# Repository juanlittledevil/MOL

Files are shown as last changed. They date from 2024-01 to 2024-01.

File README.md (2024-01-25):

# MOL

Dual ADSR/VCA combo module for Eurorack.

For more details check my blog post here: www.scruffycatstudios.com/posts/degvca/
part 2 here: www.scruffycatstudios.com/posts/degvca-part2/
And YouTube here: https://www.youtube.com/watch?v=CZ0J_sP1nE4&list=PLdO1IhDAhMdK4l8dJ0V3lOzin-maOEFXo

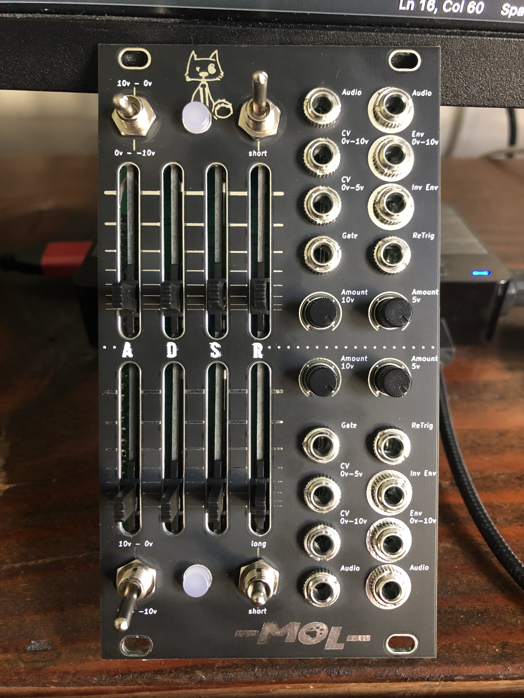
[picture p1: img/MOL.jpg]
MOL


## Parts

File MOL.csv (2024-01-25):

Source: | /Users/juan/KiCad/projects/DEGVCA/DEGVCA.kicad_sch
Date: | 2023 December 11, Monday 09:53:17
Tool: | Eeschema 7.0.1-0
Generator: | /Applications/KiCad/KiCad.app/Contents/SharedSupport/plugins/bom_csv_grouped_by_value.py
Component Count: | 174
Collated Components:
Item | Qty | Reference(s) | Value | LibPart | Footprint | Datasheet | DNP
1 | 6 | C1, C2, C8, C9, C19, C20 | 10n | *SCS:C-THL | Capacitor_THT:C_Disc_D4.3mm_W1.9mm_P5.00mm | ~
2 | 10 | C3, C4, C11, C12, C13, C14, C15, C16, C17, C18 | 100n | *SCS:C-THL | Capacitor_THT:C_Disc_D4.3mm_W1.9mm_P5.00mm | ~
3 | 2 | C5, C10 | 47uF | *SCS:C_Polarized_THL | Capacitor_THT:CP_Radial_D5.0mm_P2.50mm | ~
4 | 2 | C6, C7 | 10uF | Device:C_Polarized | Capacitor_THT:CP_Radial_D5.0mm_P2.50mm | ~
5 | 2 | C21, C22 | 1n | *SCS:C-THL | Capacitor_THT:C_Disc_D4.3mm_W1.9mm_P5.00mm | ~
6 | 2 | C23, C24 | 1u | *SCS:C-THL | Capacitor_THT:C_Disc_D4.3mm_W1.9mm_P5.00mm | ~
7 | 2 | D1, D2 | Schottky | *SCS:D_Schottky-THL | *SCS_ScruffyCat:D_DO-35_SOD27_P2.54mm_Vertical_KathodeUp | ~
8 | 16 | D3, D4, D5, D6, D7, D8, D9, D10, D11, D12, D13, D14, D15, D16, D17, D18 | 1N4148 | *SCS:D-THL | *SCS_ScruffyCat:D_DO-35_SOD27_P2.54mm_Vertical_KathodeUp | ~
9 | 1 | D19 | LED A | *SCS:LED | LED_THT:LED_D3.0mm | ~
10 | 1 | D20 | LED B | *SCS:LED | LED_THT:LED_D3.0mm | ~
11 | 2 | FB1, FB2 | FerriteBead | Device:FerriteBead | Resistor_THT:R_Axial_DIN0411_L9.9mm_D3.6mm_P5.08mm_Vertical | ~
12 | 1 | J1 | EuroRack Power | Connector_Generic:Conn_02x05_Odd_Even | Connector_IDC:IDC-Header_2x05_P2.54mm_Vertical | ~
13 | 1 | J2 | Gate In A | *SCS:Audio_Jack_Switch | *SCS_ScruffyCat:Jack_3.5mm_QingPu_thonk-PJ398SM_Vertical_CircularHoles | ~
14 | 1 | J3 | Gate In B | *SCS:Audio_Jack_Switch | *SCS_ScruffyCat:Jack_3.5mm_QingPu_thonk-PJ398SM_Vertical_CircularHoles | ~
15 | 1 | J4 | Audio In A | *SCS:Audio_Jack_Switch | *SCS_ScruffyCat:Jack_3.5mm_QingPu_thonk-PJ398SM_Vertical_CircularHoles | ~
16 | 1 | J5 | Audio In B | *SCS:Audio_Jack_Switch | *SCS_ScruffyCat:Jack_3.5mm_QingPu_thonk-PJ398SM_Vertical_CircularHoles | ~
17 | 1 | J6 | Audio Out A | *SCS:Audio_Jack_Switch | *SCS_ScruffyCat:Jack_3.5mm_QingPu_thonk-PJ398SM_Vertical_CircularHoles | ~
18 | 1 | J7 | Audio Out B | *SCS:Audio_Jack_Switch | *SCS_ScruffyCat:Jack_3.5mm_QingPu_thonk-PJ398SM_Vertical_CircularHoles | ~
19 | 1 | J8 | Inv CV Out A (10v - 0v) | *SCS:Audio_Jack_Switch | *SCS_ScruffyCat:Jack_3.5mm_QingPu_thonk-PJ398SM_Vertical_CircularHoles | ~
20 | 1 | J9 | Inv CV Out B (10v - 0v) | *SCS:Audio_Jack_Switch | *SCS_ScruffyCat:Jack_3.5mm_QingPu_thonk-PJ398SM_Vertical_CircularHoles | ~
21 | 1 | J10 | CV Out A (0v - 10v) | *SCS:Audio_Jack_Switch | *SCS_ScruffyCat:Jack_3.5mm_QingPu_thonk-PJ398SM_Vertical_CircularHoles | ~
22 | 1 | J11 | CV Out B (0v - 10v) | *SCS:Audio_Jack_Switch | *SCS_ScruffyCat:Jack_3.5mm_QingPu_thonk-PJ398SM_Vertical_CircularHoles | ~
23 | 1 | J12 | CV In A (0v - 5v) | *SCS:Audio_Jack_Switch | *SCS_ScruffyCat:Jack_3.5mm_QingPu_thonk-PJ398SM_Vertical_CircularHoles | ~
24 | 1 | J13 | CV In B (0v - 5v) | *SCS:Audio_Jack_Switch | *SCS_ScruffyCat:Jack_3.5mm_QingPu_thonk-PJ398SM_Vertical_CircularHoles | ~
25 | 1 | J14 | Re-Trigger A | *SCS:Audio_Jack_Switch | *SCS_ScruffyCat:Jack_3.5mm_QingPu_thonk-PJ398SM_Vertical_CircularHoles | ~
26 | 1 | J15 | Re-Trigger B | *SCS:Audio_Jack_Switch | *SCS_ScruffyCat:Jack_3.5mm_QingPu_thonk-PJ398SM_Vertical_CircularHoles | ~
27 | 1 | J16 | CV In A (0v - 10v) | *SCS:Audio_Jack_Switch | *SCS_ScruffyCat:Jack_3.5mm_QingPu_thonk-PJ398SM_Vertical_CircularHoles | ~
28 | 1 | J17 | CV In B (0v - 10v) | *SCS:Audio_Jack_Switch | *SCS_ScruffyCat:Jack_3.5mm_QingPu_thonk-PJ398SM_Vertical_CircularHoles | ~
29 | 4 | J18, J19, J20, J21 | Screw Hole | Connector:Conn_01x01_Female | *SCS_ScruffyCat:ScrewHole_Oval | ~
30 | 8 | Q1, Q2, Q3, Q4, Q5, Q6, Q9, Q10 | BC547 | Transistor_BJT:BC547 | Package_TO_SOT_THT:TO-92_Wide | https://www.onsemi.com/pub/Collateral/BC550-D.pdf
31 | 2 | Q7, Q8 | 2N3906 | Transistor_BJT:2N3906 | Package_TO_SOT_THT:TO-92_Wide | https://www.onsemi.com/pub/Collateral/2N3906-D.PDF
32 | 6 | R1, R2, R6, R18, R55, R57 | 10k | *SCS:R-THL | Resistor_THT:R_Axial_DIN0207_L6.3mm_D2.5mm_P2.54mm_Vertical | ~
33 | 6 | R3, R5, R7, R15, R17, R19 | 4.7k | *SCS:R-THL | Resistor_THT:R_Axial_DIN0207_L6.3mm_D2.5mm_P2.54mm_Vertical | ~
34 | 2 | R4, R16 | 22k | *SCS:R-THL | Resistor_THT:R_Axial_DIN0207_L6.3mm_D2.5mm_P2.54mm_Vertical | ~
35 | 6 | R8, R9, R11, R20, R21, R22 | 22 | *SCS:R-THL | Resistor_THT:R_Axial_DIN0207_L6.3mm_D2.5mm_P2.54mm_Vertical | ~
36 | 2 | R10, R23 | 27k | *SCS:R-THL | Resistor_THT:R_Axial_DIN0207_L6.3mm_D2.5mm_P2.54mm_Vertical | ~
37 | 8 | R12, R26, R30, R33, R42, R44, R47, R53 | 1k | *SCS:R-THL | Resistor_THT:R_Axial_DIN0207_L6.3mm_D2.5mm_P2.54mm_Vertical | ~
38 | 2 | R13, R24 | 39k | *SCS:R-THL | Resistor_THT:R_Axial_DIN0207_L6.3mm_D2.5mm_P2.54mm_Vertical | ~
39 | 2 | R14, R25 | 150k | *SCS:R-THL | Resistor_THT:R_Axial_DIN0207_L6.3mm_D2.5mm_P2.54mm_Vertical | ~
40 | 16 | R27, R36, R45, R46, R52, R54, R59, R60, R61, R62, R64, R65, R71, R72, R73, R74 | 100k | *SCS:R-THL | Resistor_THT:R_Axial_DIN0207_L6.3mm_D2.5mm_P2.54mm_Vertical | ~
41 | 4 | R28, R29, R37, R38 | 330 | *SCS:R-THL | Resistor_THT:R_Axial_DIN0207_L6.3mm_D2.5mm_P2.54mm_Vertical | ~
42 | 2 | R31, R43 | 36k | *SCS:R-THL | Resistor_THT:R_Axial_DIN0207_L6.3mm_D2.5mm_P2.54mm_Vertical | ~
43 | 2 | R32, R41 | 6.8k | *SCS:R-THL | Resistor_THT:R_Axial_DIN0207_L6.3mm_D2.5mm_P2.54mm_Vertical | ~
44 | 2 | R34, R40 | 33k | *SCS:R-THL | Resistor_THT:R_Axial_DIN0207_L6.3mm_D2.5mm_P2.54mm_Vertical | ~
45 | 7 | R35, R39, R51, R63, R66, R67, R68 | 330k | *SCS:R-THL | Resistor_THT:R_Axial_DIN0207_L6.3mm_D2.5mm_P2.54mm_Vertical | ~
46 | 1 | R48 | 68k | *SCS:R-THL | Resistor_THT:R_Axial_DIN0207_L6.3mm_D2.5mm_P2.54mm_Vertical | ~
47 | 1 | R49 | 47k | *SCS:R-THL | Resistor_THT:R_Axial_DIN0207_L6.3mm_D2.5mm_P2.54mm_Vertical | ~
48 | 1 | R50 | 470k | *SCS:R-THL | Resistor_THT:R_Axial_DIN0207_L6.3mm_D2.5mm_P2.54mm_Vertical | ~
49 | 4 | R56, R58, R69, R70 | 220 | *SCS:R-THL | Resistor_THT:R_Axial_DIN0207_L6.3mm_D2.5mm_P2.54mm_Vertical | ~
50 | 1 | REF_ADJ_A1 | 5k | Device:R_Potentiometer_Trim | *SCS_ScruffyCat:Potentiometer_Trim_Vertical_THL | ~
51 | 1 | RV1 | Attack A | *SCS:R_Potentiometer-THL | Potentiometer_THT:Potentiometer_Alpha_RD901F-40-00D_Single_Vertical_CircularHoles | ~
52 | 3 | RV2, RV4, RV8 | Decay A | *SCS:R_Potentiometer-THL | Potentiometer_THT:Potentiometer_Alpha_RD901F-40-00D_Single_Vertical_CircularHoles | ~
53 | 1 | RV3 | Sustain A | *SCS:R_Potentiometer-THL | Potentiometer_THT:Potentiometer_Alpha_RD901F-40-00D_Single_Vertical_CircularHoles | ~
54 | 1 | RV5 | Attack B | *SCS:R_Potentiometer-THL | Potentiometer_THT:Potentiometer_Alpha_RD901F-40-00D_Single_Vertical_CircularHoles | ~
55 | 1 | RV6 | Decay B | *SCS:R_Potentiometer-THL | Potentiometer_THT:Potentiometer_Alpha_RD901F-40-00D_Single_Vertical_CircularHoles | ~
56 | 1 | RV7 | Sustain B | *SCS:R_Potentiometer-THL | Potentiometer_THT:Potentiometer_Alpha_RD901F-40-00D_Single_Vertical_CircularHoles | ~
57 | 4 | RV9, RV10, RV11, RV12 | 100k | *SCS:R_Potentiometer-THL | Potentiometer_THT:Potentiometer_Alpha_RD901F-40-00D_Single_Vertical_CircularHoles | ~
58 | 2 | SW1, SW2 | SW_Push_LED | Switch:SW_Push_LED | *SCS_ScruffyCat:SW_PushButton_LED_E-Type-A | ~
59 | 1 | SW3 | Inv Offset A | *SCS:SW_SPDT | *SCS_ScruffyCat:SW_Toggle_Blue_wSlots | ~
60 | 1 | SW4 | Inv Offset B | *SCS:SW_SPDT | *SCS_ScruffyCat:SW_Toggle_Blue_wSlots | ~
61 | 1 | TP1-(5v)1 | TestPoint | Connector:TestPoint | Connector_Pin:Pin_D0.9mm_L10.0mm_W2.4mm_FlatFork | ~
62 | 1 | U1 | LM556 | *SCS:LM556 | Package_DIP:DIP-14_W7.62mm_Socket | http://www.ti.com/lit/ds/symlink/lm556.pdf
63 | 3 | U2, U4, U5 | TL074 | *SCS:TL074 |  | http://www.ti.com/lit/ds/symlink/tl071.pdf
64 | 1 | U3 | LM13700 | Amplifier_Operational:LM13700 |  | http://www.ti.com/lit/ds/symlink/lm13700.pdf

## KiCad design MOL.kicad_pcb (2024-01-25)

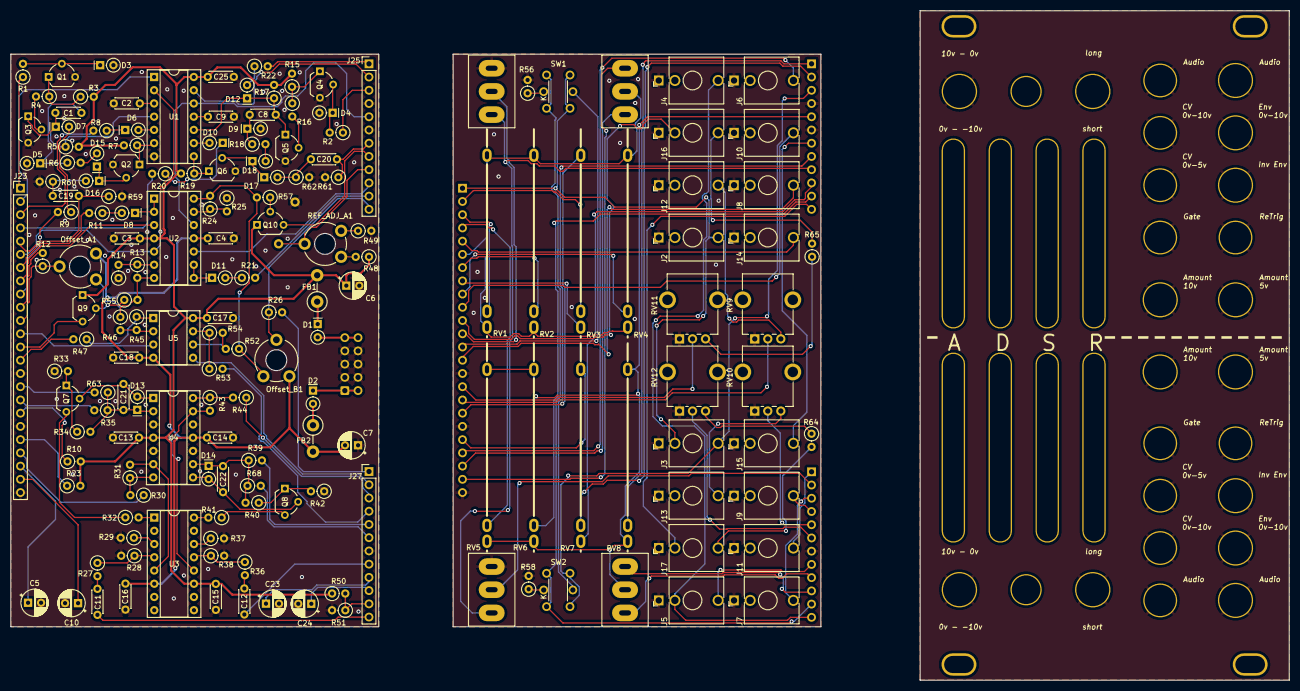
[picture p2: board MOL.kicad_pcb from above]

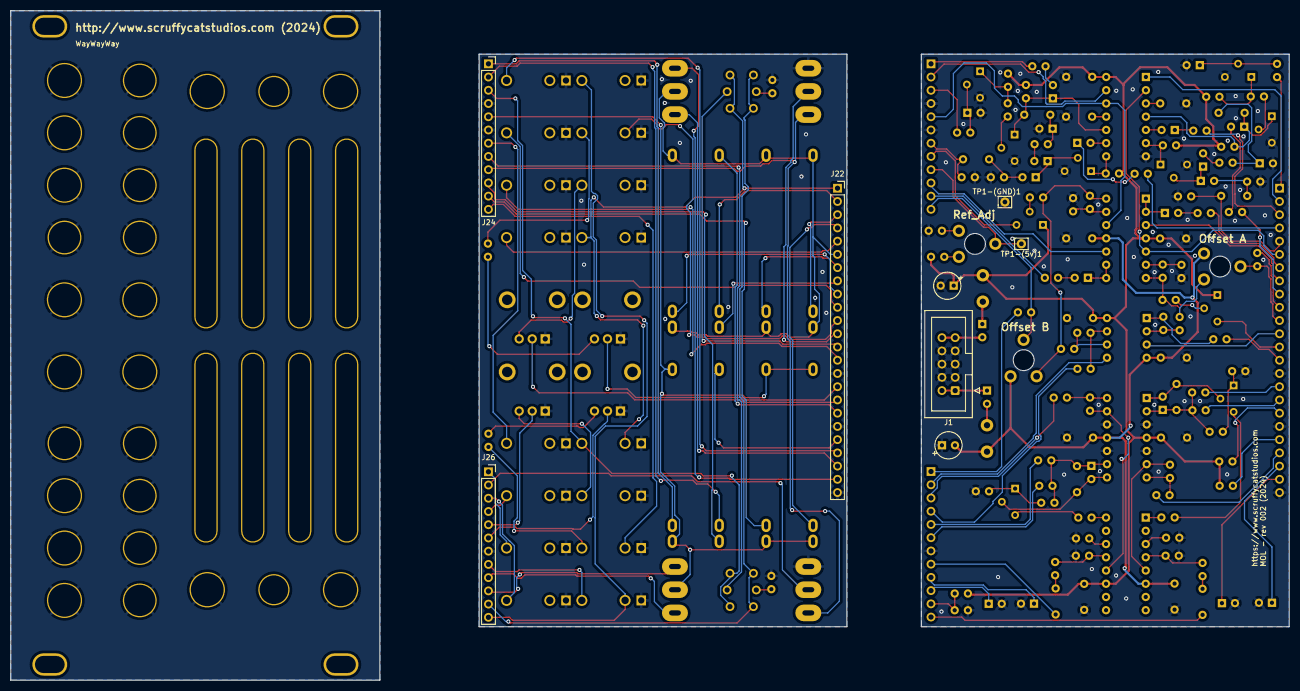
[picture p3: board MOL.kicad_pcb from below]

Board: 2 copper layers, 245.4 x 128.5 mm, 210 parts (6 on the bottom side), 161 nets.

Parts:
BH1, BH2: LED Button; LED-ButtonHole
C1, C2, C8, C9, C19, C20: 10n; C_Disc_D4.3mm_W1.9mm_P5.00mm
C3, C4, C11, C12, C13, C14, C15, C16, C17, C18, C25: 100n; C_Disc_D4.3mm_W1.9mm_P5.00mm
C5, C23: 47uF; CP_Radial_D5.0mm_P2.50mm
C6, C7: 10uF; CP_Radial_D5.0mm_P2.50mm
C10, C24: 4.7uF; CP_Radial_D5.0mm_P2.50mm
C21, C22: 1n; C_Disc_D4.3mm_W1.9mm_P5.00mm
D1, D2: Schottky; D_DO-35_SOD27_P2.54mm_Vertical_KathodeUp
D3, D4, D5, D6, D7, D8, D9, D10, D11, D12, D13, D14, D15, D16, D17, D18: 1N4148; D_DO-35_SOD27_P2.54mm_Vertical_KathodeUp
FB1, FB2: FerriteBead; R_Axial_DIN0411_L9.9mm_D3.6mm_P5.08mm_Vertical
J1: EuroRack Power; IDC-Header_2x05_P2.54mm_Vertical
J2: Gate In A; Jack_3.5mm_QingPu_thonk-PJ398SM_Vertical_CircularHoles
J3: Gate In B; Jack_3.5mm_QingPu_thonk-PJ398SM_Vertical_CircularHoles
J4: Audio In A_(C); Jack_3.5mm_QingPu_thonk-PJ398SM_Vertical_CircularHoles
J5: Audio In B_(C); Jack_3.5mm_QingPu_thonk-PJ398SM_Vertical_CircularHoles
J6: Audio Out A_(C); Jack_3.5mm_QingPu_thonk-PJ398SM_Vertical_CircularHoles
J7: Audio Out B_(C); Jack_3.5mm_QingPu_thonk-PJ398SM_Vertical_CircularHoles
J8: Inv CV Out A (10v - 0v); Jack_3.5mm_QingPu_thonk-PJ398SM_Vertical_CircularHoles
J9: Inv CV Out B (10v - 0v); Jack_3.5mm_QingPu_thonk-PJ398SM_Vertical_CircularHoles
J10: CV Out A (0v - 10v); Jack_3.5mm_QingPu_thonk-PJ398SM_Vertical_CircularHoles
J11: CV Out B (0v - 10v); Jack_3.5mm_QingPu_thonk-PJ398SM_Vertical_CircularHoles
J12: CV In A (0v - 5v); Jack_3.5mm_QingPu_thonk-PJ398SM_Vertical_CircularHoles
J13: CV In B (0v - 5v); Jack_3.5mm_QingPu_thonk-PJ398SM_Vertical_CircularHoles
J14: Re-Trigger A_(C); Jack_3.5mm_QingPu_thonk-PJ398SM_Vertical_CircularHoles
J15: Re-Trigger B_(C); Jack_3.5mm_QingPu_thonk-PJ398SM_Vertical_CircularHoles
J16: CV In A (0v - 10v); Jack_3.5mm_QingPu_thonk-PJ398SM_Vertical_CircularHoles
J17: CV In B (0v - 10v); Jack_3.5mm_QingPu_thonk-PJ398SM_Vertical_CircularHoles
J18, J19, J20, J21: Screw Hole; ScrewHole_Oval
J22: Conn_01x24_Socket; PinSocket_1x24_P2.54mm_Vertical
J23: Conn_01x24_Pin; PinHeader_1x24_P2.54mm_Vertical
J24, J26: Conn_01x12_Socket; PinSocket_1x12_P2.54mm_Vertical
J25, J27: Conn_01x12_Pin; PinHeader_1x12_P2.54mm_Vertical
JH1, JH2, JH3, JH4, JH7, JH9, JH10, JH11, JH12, JH14: 3.5mm Jack; JackHole_3.5mm
JH5, JH6, JH8, JH13, JH15, JH16: 3.5mm Jack; JackHole_3.5mm-OUT
Offset_A1: 5k; Potentiometer_Trim_Vertical_THL
Offset_B1: 5k; Potentiometer_Trim_Vertical_THL
PH1, PH2, PH3, PH4, PH5, PH6, PH7, PH8: 30mm Vertical Slider; PotHole_Slide_open_oval
PH9, PH10, PH11, PH12: Pot Jack (no-mount); PotHole_no-mount
Q1, Q2, Q3, Q4, Q5, Q6, Q9, Q10: BC547; TO-92_Wide
Q7, Q8: 2N3906; TO-92_Wide
R1, R2, R6, R18, R55, R57: 10k; R_Axial_DIN0207_L6.3mm_D2.5mm_P2.54mm_Vertical
R3, R5, R7, R15, R17, R19: 4.7k; R_Axial_DIN0207_L6.3mm_D2.5mm_P2.54mm_Vertical
R4, R16: 22k; R_Axial_DIN0207_L6.3mm_D2.5mm_P2.54mm_Vertical
R8, R9, R11, R20, R21, R22: 22; R_Axial_DIN0207_L6.3mm_D2.5mm_P2.54mm_Vertical
R10, R23, R49: 27k; R_Axial_DIN0207_L6.3mm_D2.5mm_P2.54mm_Vertical
R12, R26, R30, R33, R42, R44, R47, R53: 1k; R_Axial_DIN0207_L6.3mm_D2.5mm_P2.54mm_Vertical
R13, R24, R31, R43, R48: 39k; R_Axial_DIN0207_L6.3mm_D2.5mm_P2.54mm_Vertical
R14, R25: 150k; R_Axial_DIN0207_L6.3mm_D2.5mm_P2.54mm_Vertical
R27, R36, R45, R46, R52, R54, R59, R60, R61, R62, R64, R65: 100k; R_Axial_DIN0207_L6.3mm_D2.5mm_P2.54mm_Vertical
R28, R29, R37, R38: 330; R_Axial_DIN0207_L6.3mm_D2.5mm_P2.54mm_Vertical
R32, R41: 6.8k; R_Axial_DIN0207_L6.3mm_D2.5mm_P2.54mm_Vertical
R34, R40: 33k; R_Axial_DIN0207_L6.3mm_D2.5mm_P2.54mm_Vertical
R35, R39, R51, R63, R68: 330k; R_Axial_DIN0207_L6.3mm_D2.5mm_P2.54mm_Vertical
R50: 470k; R_Axial_DIN0207_L6.3mm_D2.5mm_P2.54mm_Vertical
R56, R58: 2.2k; R_Axial_DIN0207_L6.3mm_D2.5mm_P2.54mm_Vertical
REF_ADJ_A1: 5k; Potentiometer_Trim_Vertical_THL
RV1: Attack A; Potentiometer_Slide_open_THL
RV2: Decay A; Potentiometer_Slide_open_THL
RV3: Sustain A; Potentiometer_Slide_open_THL
RV4: Release A; Potentiometer_Slide_open_THL
RV5: Attack B; Potentiometer_Slide_open_THL
RV6: Decay B; Potentiometer_Slide_open_THL
RV7: Sustain B; Potentiometer_Slide_open_THL
RV8: Release B; Potentiometer_Slide_open_THL
RV9, RV10, RV11, RV12: 100k; Potentiometer_Alpha_RD901F-40-00D_Single_Vertical_CircularH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
SH1, SH2, SH3, SH4: Switch Jack; SwitchHole_screw-mount
SW1, SW2: SW_Push_LED; SW_PushButton_LED_E-Type-A
SW3: Inv Offset A; SW_Toggle_Blue_wSlots
SW4: Inv Offset B; SW_Toggle_Blue_wSlots
SW5: Length A; SW_Toggle_Blue_wSlots
SW6: Length B; SW_Toggle_Blue_wSlots
TP1-(5v)1, TP1-(GND)1: TestPoint; Pin_D0.9mm_L10.0mm_W2.4mm_FlatFork
U1: LM556; DIP-14_W7.62mm_Socket
U2, U4: TL074; DIP-14_W7.62mm_Socket
U3: LM13700; DIP-16_W7.62mm_Socket
U5: TL072; DIP-8_W7.62mm_Socket

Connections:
+12V: C3.1, C6.1, C13.1, C15.1, C17.1, C25.1, FB1.2, Q9.1 (C), Q10.1 (C), R3.2, R5.2, R7.2, R10.2, R15.2, R17.2, R19.2, R23.2, R48.1, R50.1, U1.14 (VCC), U2.4 (V+), U3.11 (V+), U4.4 (V+), U5.8 (V+)
-12V: C4.2, C7.2, C14.2, C16.2, C18.2, FB2.2, Offset_A1.1, Offset_B1.1, U2.11 (V-), U3.6 (V-), U4.11 (V-), U5.4 (V-)
/Control/5.4v_(C): J26.11, SW1.1, SW2.1
/Control/5v_ref: J25.9, REF_ADJ_A1.2, TP1-(5v)1.1
/Control/5v_ref_(C): J24.9, SW3.1 (A), SW4.1 (A)
/Control/Attack_1_A: J23.3, R8.2
/Control/Attack_1_A_(C): J22.3, RV1.1
/Control/Attack_1_B: J23.4, R20.2
/Control/Attack_1_B_(C): J22.4, RV5.1
/Control/Audio_In_A: C11.1, J27.12
/Control/Audio_In_A_(C): J4.2, J5.3, J26.12
/Control/Audio_In_B: C12.1, J27.8
/Control/Audio_In_B_(C): J5.2, J26.8
/Control/Audio_Out_A: J23.21, R30.1
/Control/Audio_Out_A_(C): J6.2, J22.21
/Control/Audio_Out_B: J27.3, R44.1
/Control/Audio_Out_B_(C): J7.2, J26.3
/Control/CV_In_5v_A: J23.17, R35.2
/Control/CV_In_5v_A_(C): J22.17, RV9.2
/Control/CV_In_5v_B: J27.5, R39.2
/Control/CV_In_5v_B_(C): J26.5, RV10.2
/Control/CV_In_10v_A: J23.16, R63.2
/Control/CV_In_10v_A_(C): J22.16, RV11.2
/Control/CV_In_10v_B: J27.6, R68.2
/Control/CV_In_10v_B_(C): J26.6, RV12.2
/Control/Decay_1_A: J23.7, R11.2
/Control/Decay_1_A_(C): J22.7, RV2.1
/Control/Decay_1_B: J25.11, R21.2
/Control/Decay_1_B_(C): J24.11, RV6.1
/Control/Discharge_A: J23.6, U1.2 (THR), U2.5 (+)
/Control/Discharge_A_(C): J22.6, RV1.2, RV1.3, RV2.2, RV2.3, RV4.2, RV4.3, SW5.2 (B)
/Control/Discharge_B: J25.5, U1.12 (THR), U2.12 (+)
/Control/Discharge_B_(C): J24.5, RV5.2, RV5.3, RV6.2, RV6.3, RV8.2, RV8.3, SW6.2 (B)
/Control/EG_LED_Anode_A: J23.13, Q9.3 (E)
/Control/EG_LED_Anode_A_(C): J22.13, SW1.4 (A)
/Control/EG_LED_Anode_B: J25.8, Q10.3 (E)
/Control/EG_LED_Anode_B_(C): J24.8, SW2.4 (A)
/Control/Env_A: J23.11, Offset_A1.2, R12.1
/Control/Env_A_(C): J16.3, J22.11
/Control/Env_B: J25.12, Offset_B1.2, R26.1
/Control/Env_B_(C): J17.3, J24.12
/Control/Env_Out_A: J23.10, R12.2
/Control/Env_Out_A_(C): J10.2, J22.10
/Control/Env_Out_B: J27.1, R26.2
/Control/Env_Out_B_(C): J11.2, J26.1
/Control/Gate_in_A: J23.1, R1.1
/Control/Gate_in_A_(C): J2.2, J3.3, J22.1, SW1.2
/Control/Gate_in_B: J25.3, R2.1
/Control/Gate_in_B_(C): J3.2, J24.3, SW2.2
/Control/InvEnv_Out_A: J23.14, R47.2
/Control/InvEnv_Out_A_(C): J8.2, J22.14
/Control/InvEnv_Out_B: J27.4, R53.2
/Control/InvEnv_Out_B_(C): J9.2, J26.4
/Control/Long_A: C5.1, J23.22
/Control/Long_A_(C): J22.22, SW5.1 (A)
/Control/Long_B: C23.1, J27.9
/Control/Long_B_(C): J26.9, SW6.1 (A)
/Control/ReTrigger_A: C19.1, J23.5, R59.1
/Control/ReTrigger_A_(C): J14.2, J22.5
/Control/ReTrigger_B: C20.1, J25.7, R61.1
/Control/ReTrigger_B_(C): J15.2, J24.7
/Control/Release_1_A: J23.9, R9.2
/Control/Release_1_A_(C): J22.9, RV4.1
/Control/Release_1_B: J25.1, R22.2
/Control/Release_1_B_(C): J24.1, RV8.1
/Control/Short_A: C10.1, J23.23
/Control/Short_A_(C): J22.23, SW5.3 (C)
/Control/Short_B: C24.1, J27.10
/Control/Short_B_(C): J26.10, SW6.3 (C)
/Control/Sustain_1_A: J23.2, U1.1 (DIS)
/Control/Sustain_1_A_(C): J22.2, RV3.1
/Control/Sustain_1_B: J25.2, U1.13 (DIS)
/Control/Sustain_1_B_(C): J24.2, RV7.1
/Control/Sustain_2_A: J23.8, U2.3 (+)
/Control/Sustain_2_A_(C): J22.8, RV3.2
/Control/Sustain_2_B: J25.10, U2.10 (+)
/Control/Sustain_2_B_(C): J24.10, RV7.2
/Control/Sustain_3_A: J23.18, R10.1
/Control/Sustain_3_A_(C): J22.18, RV3.3
/Control/Sustain_3_B: J23.20, R23.1
/Control/Sustain_3_B_(C): J22.20, RV7.3
/Control/inv_offset_A: J23.12, U5.3 (+)
/Control/inv_offset_A_(C): J22.12, SW3.2 (B)
/Control/inv_offset_B: J27.2, U5.5 (+)
/Control/inv_offset_B_(C): J26.2, SW4.2 (B)
/Fastest ADSR in the West/5.4v_Ref: J27.11, R50.2, R51.1
/Fastest ADSR in the West/Reset_A: C1.1, D7.1 (K), Q3.1 (C), R5.1, U1.4 (R)
/Fastest ADSR in the West/Reset_B: C8.1, D12.1 (K), Q5.1 (C), R17.1, U1.10 (R)
/Power Supply/EuroPower-neg: D2.1 (K), J1.1, J1.2
/Power Supply/EuroPower-pos: D1.2 (A), J1.9, J1.10
/Power Supply/PolNeg: D2.2 (A), FB2.1
/Power Supply/PolPlus: D1.1 (K), FB1.1
GND: C2.2, C3.2, C4.1, C5.2, C6.2, C7.1, C9.2, C10.2, C13.2, C14.1, C15.2, C16.1, C17.2, C18.1, C23.2, C24.2, C25.2, D3.2 (A), D4.2 (A), D5.2 (A), D9.2 (A), J1.3, J1.4, J1.5, J1.6, J1.7, J1.8, J2.1, J3.1, J4.1, J5.1, J6.1, J7.1, J8.1, J9.1, J10.1, J11.1, J12.1, J13.1, J14.1, J15.1, J16.1, J17.1, J22.15, J22.19, J22.24, J23.15, J23.19, J23.24, J24.4, J24.6, J25.4, J25.6, J26.7, J27.7, JH1.1, JH2.1, JH3.1, JH4.1, JH5.1, JH6.1, JH7.1, JH8.1, JH9.1, JH10.1, JH11.1, JH12.1, JH13.1, JH14.1, JH15.1, JH16.1, PH9.1, PH10.1, PH11.1, PH12.1, Q1.3 (E), Q2.3 (E), Q3.3 (E), Q4.3 (E), Q5.3 (E), Q6.3 (E), R14.1, R25.1, R28.2, R29.2, R33.1, R37.2, R38.2, R42.1, R49.2, R51.2, R56.2, R58.2, R59.2, R60.2, R61.2, R62.2, RV9.1, RV10.1, RV11.1, RV12.1, SH1.1, SH2.1, SH3.1, SH4.1, SW3.3 (C), SW4.3 (C), TP1-(GND)1.1, U1.7 (GND), U4.3 (+), U4.5 (+), U4.10 (+), U4.12 (+)
unnamed: C11.2, R27.2
unnamed: C12.2, R36.2
unnamed: D3.1 (K), Q1.2 (B), R1.2
unnamed: D4.1 (K), Q4.2 (B), R2.2
unnamed: C1.2, D5.1 (K), R6.1
unnamed: D6.2 (A), U1.5 (Q)
unnamed: D6.1 (K), R8.1
unnamed: D7.2 (A), R9.1
unnamed: D8.2 (A), R11.1
unnamed: D8.1 (K), U2.1, U2.2 (-)
unnamed: C8.2, D9.1 (K), R18.1
unnamed: D10.2 (A), U1.9 (Q)
unnamed: D10.1 (K), R20.1
unnamed: D11.2 (A), R21.1
unnamed: D11.1 (K), U2.8, U2.9 (-)
unnamed: D12.2 (A), R22.1
unnamed: C21.2, D13.2 (A), Q7.2 (B), U4.1
unnamed: C21.1, D13.1 (K), R34.2, R35.1, R63.1, U4.2 (-)
unnamed: C22.2, D14.2 (A), Q8.2 (B), U4.8
unnamed: C22.1, D14.1 (K), R39.1, R40.2, R68.1, U4.9 (-)
unnamed: D15.2 (A), R6.2
unnamed: D15.1 (K), D16.1 (K), Q2.2 (B)
unnamed: C19.2, D16.2 (A), R60.1
unnamed: C20.2, D17.2 (A), R62.1
unnamed: D17.1 (K), D18.1 (K), Q6.2 (B)
unnamed: D18.2 (A), R18.2
unnamed: J12.2, RV9.3
unnamed: J13.2, RV10.3
unnamed: J16.2, R65.2
unnamed: J17.2, R64.2
unnamed: Offset_A1.3, R13.2, R46.1, R55.2, U2.7
unnamed: Offset_B1.3, R24.2, R52.1, R57.2, U2.14
unnamed: Q1.1 (C), R3.1, R4.1
unnamed: Q2.1 (C), R7.1, U1.6 (TR)
unnamed: Q3.2 (B), R4.2
unnamed: Q4.1 (C), R15.1, R16.1
unnamed: Q5.2 (B), R16.2
unnamed: Q6.1 (C), R19.1, U1.8 (TR)
unnamed: Q7.3 (C), R32.1
unnamed: Q7.1 (E), R33.2, R34.1
unnamed: Q8.3 (C), R41.1
unnamed: Q8.1 (E), R40.1, R42.2
unnamed: Q9.2 (B), R55.1
unnamed: Q10.2 (B), R57.1
unnamed: R30.2, R31.1, U4.7
unnamed: R32.2, U3.1
unnamed: R41.2, U3.16
unnamed: R43.1, R44.2, U4.14
unnamed: R45.1, R47.1, U5.1
unnamed: R48.2, REF_ADJ_A1.3
unnamed: R49.1, REF_ADJ_A1.1
unnamed: R53.1, R54.1, U5.7
unnamed: R64.1, RV12.3
unnamed: R65.1, RV11.3
unnamed: R56.1, SW1.3 (K)
unnamed: R58.1, SW2.3 (K)
unnamed: C2.1, U1.3 (CV)
unnamed: C9.1, U1.11 (CV)
unnamed: R13.1, R14.2, U2.6 (-)
unnamed: R24.1, R25.2, U2.13 (-)
unnamed: R37.1, U3.14 (+)
unnamed: R36.1, R38.1, U3.13 (-)
unnamed: R29.1, U3.3 (+)
unnamed: R27.1, R28.1, U3.4 (-)
unnamed: R31.2, U3.5, U4.6 (-)
unnamed: R43.2, U3.12, U4.13 (-)
unnamed: R45.2, R46.2, U5.2 (-)
unnamed: R52.2, R54.2, U5.6 (-)
